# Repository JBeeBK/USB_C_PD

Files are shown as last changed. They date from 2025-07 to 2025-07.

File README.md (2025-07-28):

# USB-C PD Power Meter and Debug Tool

This project is a compact, professional-grade USB-C Power Delivery (PD) debug tool and power meter. **Not finished yet tho.**
It’s designed to showcase modern hardware stuffs (USB-C, PD negotiation, embedded control, current/voltage sensing).
---

## Features

- **USB-C PD Sink (STUSB4500)**: negotiates 5 V / 9 V / 12 V / 15 V / 20 V profiles.  
- **Current and Voltage Monitoring**: INA219 + voltage divider for real-time display.  
- **I²C OLED Menu System**: user-selectable voltage and output control with buttons.  
- **Temperature Monitoring**: TMP112 tracks board temperature for safety.  
- **Visual Indicators**: LEDs show active voltage selection (5 V–20 V).  
- **Output Flexibility**: USB-C and screw terminal outputs (user selects output).  
- **MCU Control**: STM32G030 (TSOP-20) manages I²C devices, UI, and safety cutoffs.  
- **Designed in KiCad 9**: manufacturable layout, not just breadboard-friendly.

---

## Current Status

- **Schematic completed** (`00_Hardware`).  
- **First-round PCB layout completed** (see image below).  
- full check and BOM completion are next

---

## Board Preview

### Top View (First Layout)
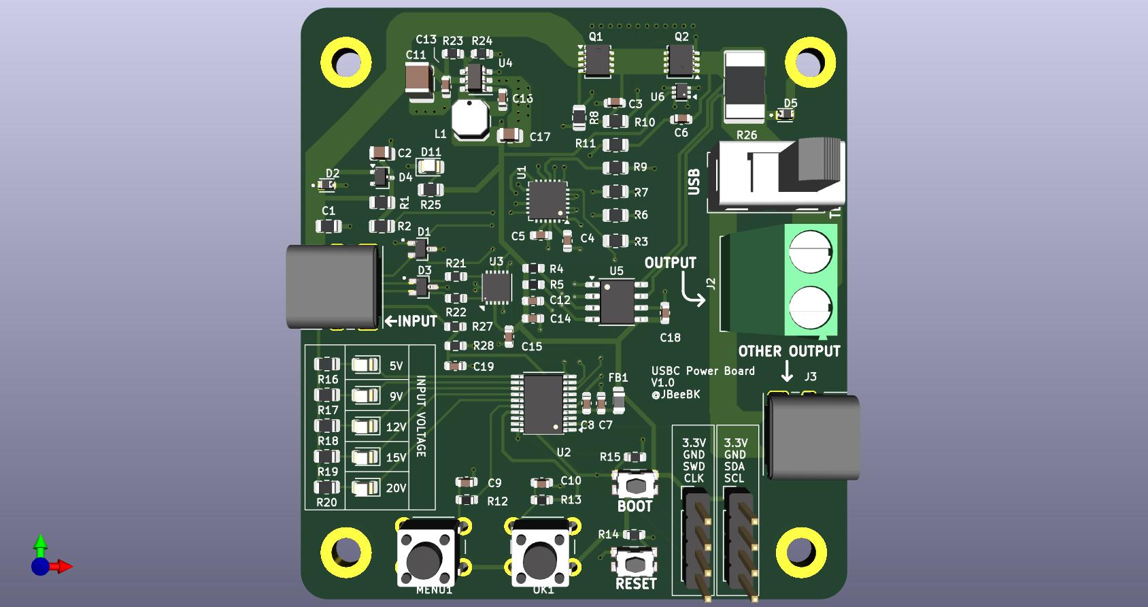
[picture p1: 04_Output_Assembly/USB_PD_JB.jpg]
Board Top


---

## Repository Structure
- 00_Hardware/ # KiCad schematic, PCB, footprints, symbols.
- 01_Docs/ # Design notes, app notes, calculations.
- 02_Datasheets/ # Datasheets here.
- 03_Output_PCB/ # Gerbers.
- 04_Output_Assembly/ # Board renders and fabrication files.
- USB_PD_JB-backups/ # Auto-saved KiCad backups
- output generator python script
- README.md
- .gitignore

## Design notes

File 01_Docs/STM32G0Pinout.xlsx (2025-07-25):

STM32G030F6 | Mapping | TSOP-20
Pin | Name | Function
1 | PB7 | Nope
2 | PB9 | I2C_SCL
3 | PC15 | Nope
4 | VDD | 3.3V
5 | VSS | GND
6 | NRST | Reset
7 | PA0 | Button 1
8 | PA1 | Button 2
9 | PA2 | UART RX
10 | PA3 | UART TX
11 | PA4 | LED_5V
12 | PA5 | LED_9V
13 | PA6 | LED_12V
14 | PA7 | LED_15V
15 | PA8 | LED_20V
16 | PA9 | Nope
17 | PA10 | Nope
18 | PA13 | SWDIO
19 | PA15 | BOOT/SDWCLK
20 | PB3 | I2C_SDA

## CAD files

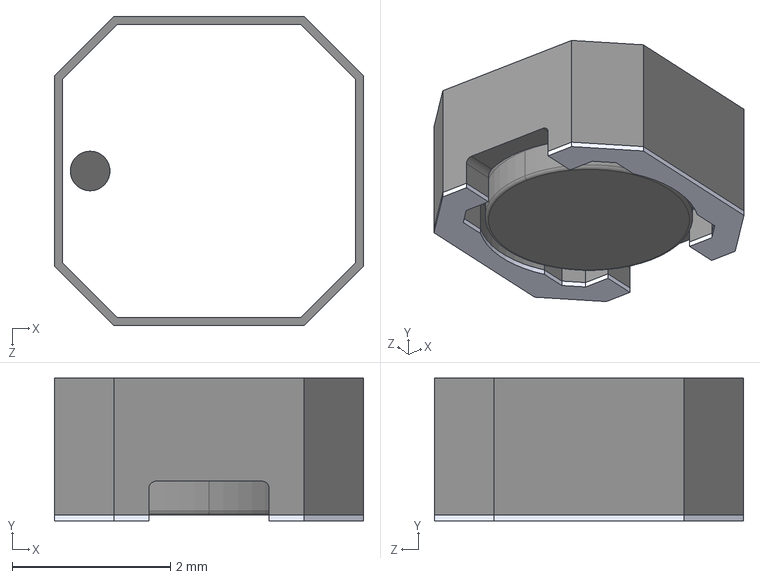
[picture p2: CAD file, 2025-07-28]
00_Hardware/Project_Footprints/LPS4018-103MRC.STEP
3.90 x 1.80 x 3.90 mm

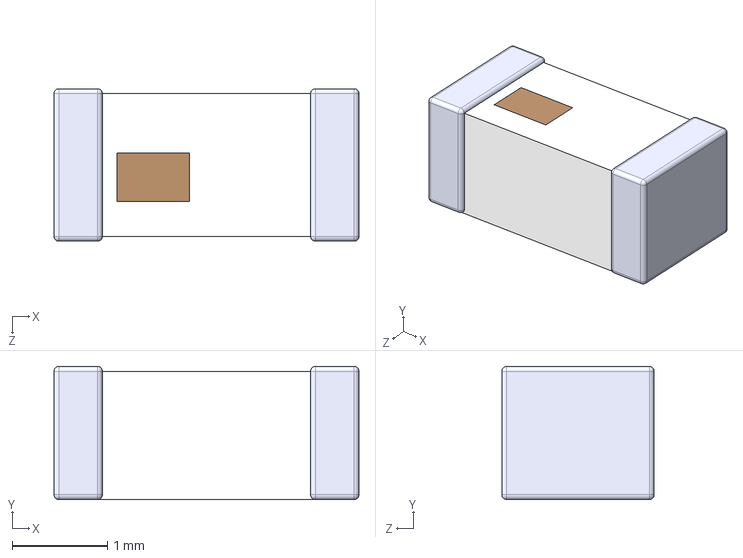
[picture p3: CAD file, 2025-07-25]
00_Hardware/Project_Footprints/2450AT18B100E.step
3.20 x 1.40 x 1.60 mm

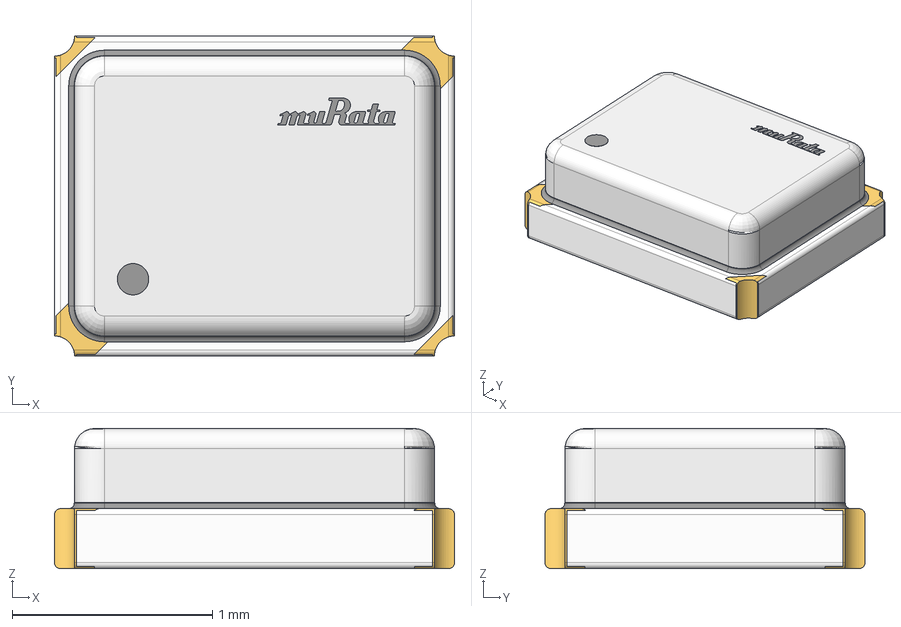
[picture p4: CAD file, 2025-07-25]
00_Hardware/Project_Footprints/XRCGB32M000F1SBJR0-.STEP
2.00 x 1.60 x 0.702 mm

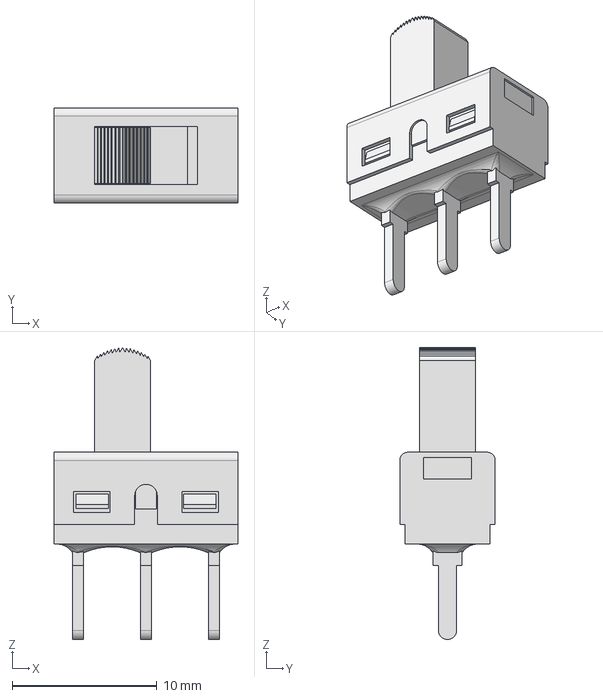
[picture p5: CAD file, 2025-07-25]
00_Hardware/Project_Footprints/500SSP1S2M2QEA.step
12.7 x 6.60 x 20.2 mm

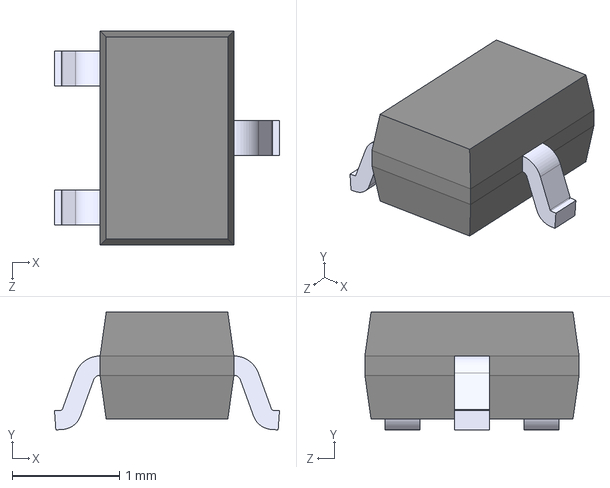
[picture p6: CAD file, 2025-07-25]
00_Hardware/Project_Footprints/ESDA25W.step
2.10 x 1.10 x 2.00 mm

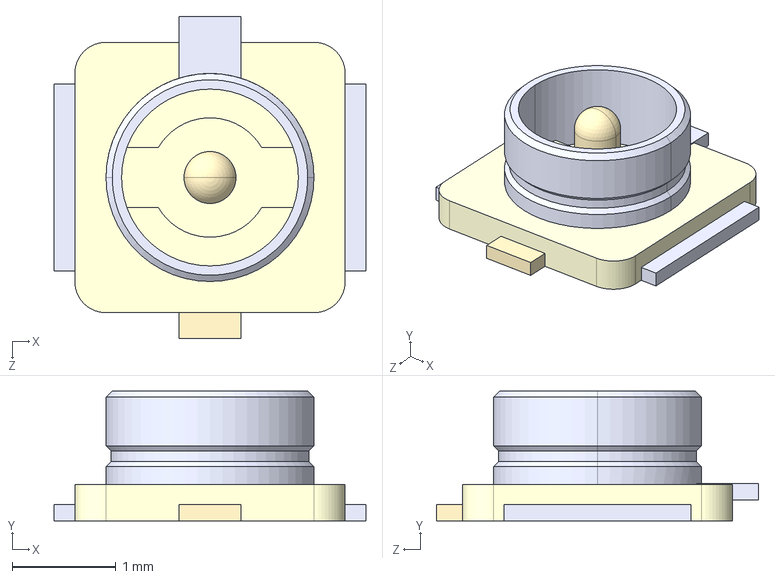
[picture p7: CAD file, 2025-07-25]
00_Hardware/Project_Footprints/U.FL-R-SMT_01_.step
3.00 x 1.25 x 3.10 mm

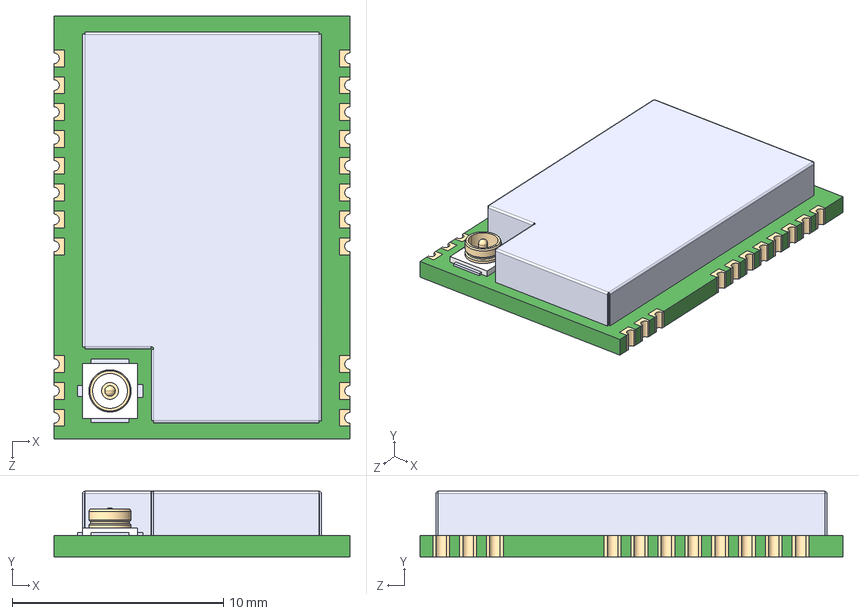
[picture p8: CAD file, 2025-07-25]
00_Hardware/Project_Footprints/E22-900M22S.step
14.0 x 3.10 x 20.0 mm

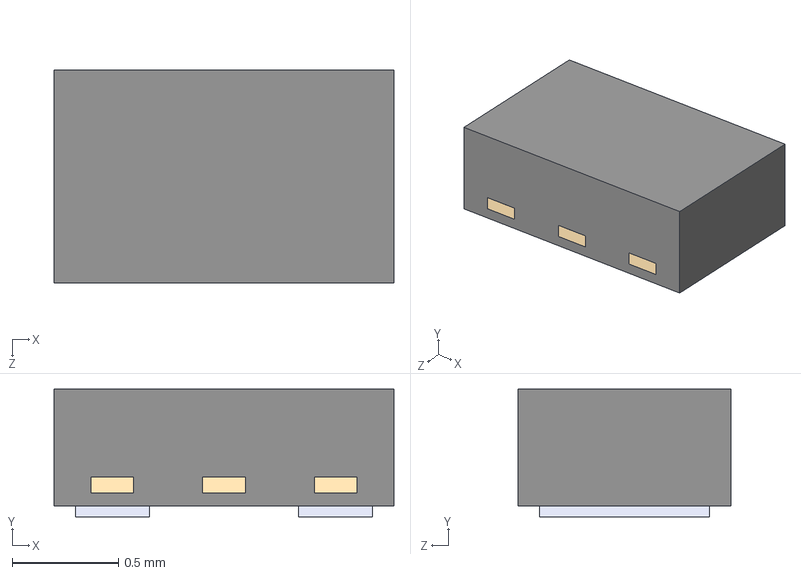
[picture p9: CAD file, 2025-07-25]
00_Hardware/Project_Footprints/ESDA25P35-1U1M.step
1.60 x 0.6 x 1.00 mm

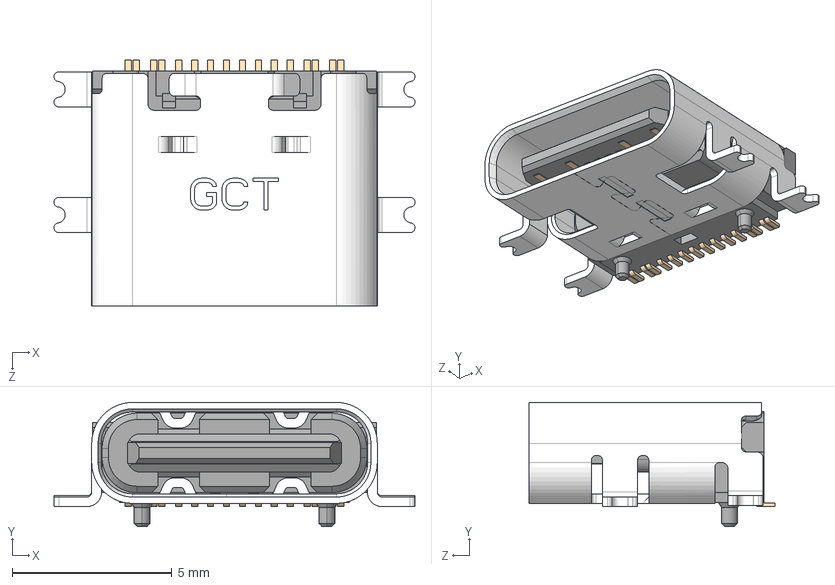
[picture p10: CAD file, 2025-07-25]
00_Hardware/Project_Footprints/USB4110-GF-A.stp
11.3 x 3.89 x 7.70 mm

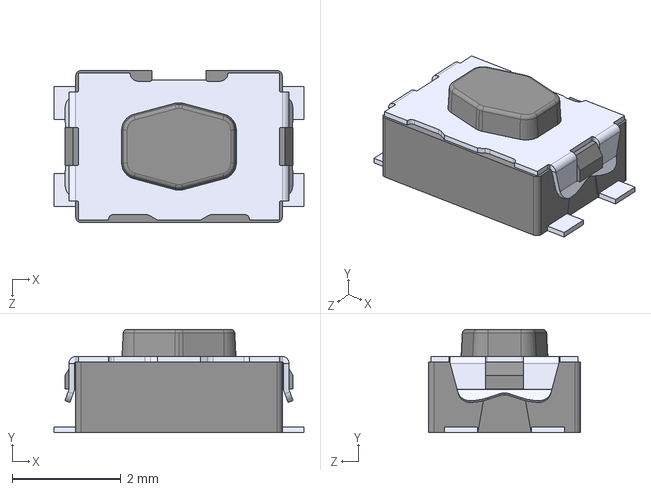
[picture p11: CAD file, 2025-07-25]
00_Hardware/Project_Footprints/KMR211NGLFS.STEP
4.60 x 1.90 x 2.80 mm

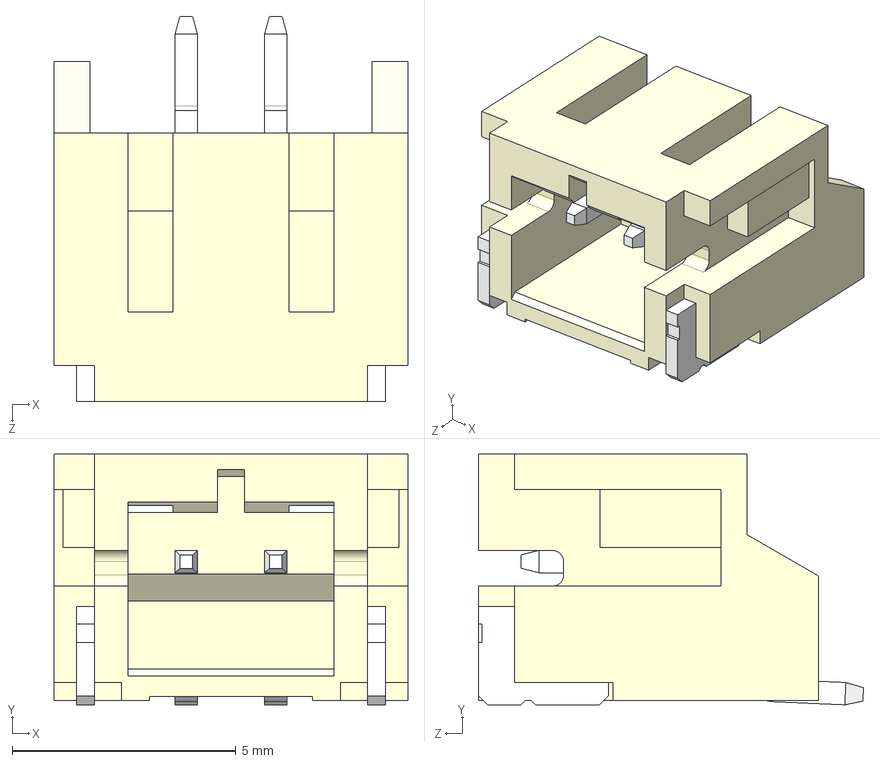
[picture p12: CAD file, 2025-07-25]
00_Hardware/Project_Footprints/S2B-PH-SM4-TB_LF__SN_.step
7.90 x 5.60 x 8.60 mm

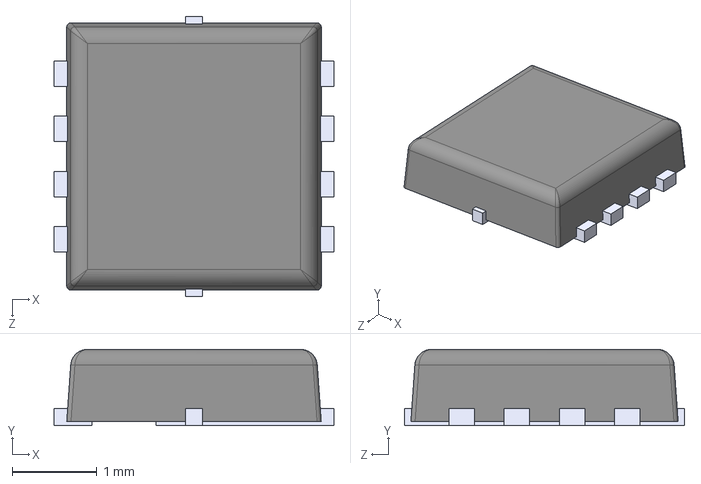
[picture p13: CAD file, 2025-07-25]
00_Hardware/Project_Footprints/STL6P3LLH6.step
3.30 x 0.9 x 3.30 mm

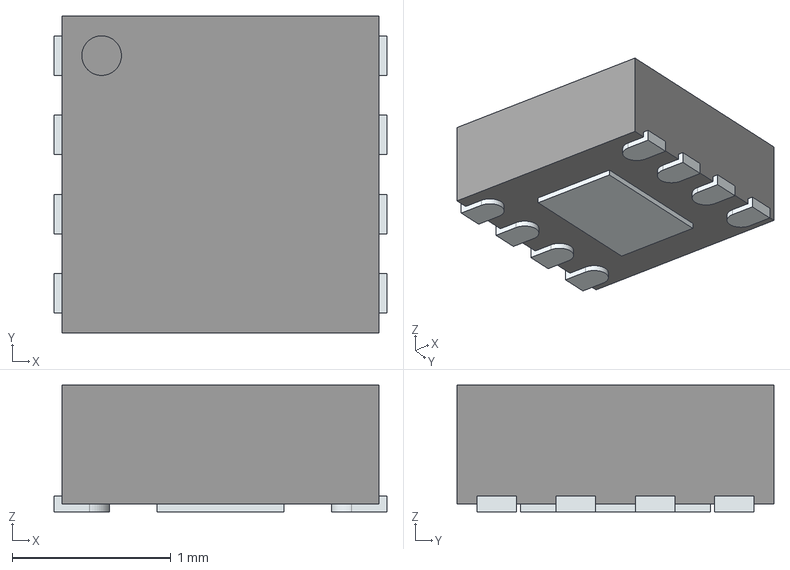
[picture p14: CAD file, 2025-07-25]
00_Hardware/Project_Footprints/MAX17048G+T10.stp
2.10 x 2.00 x 0.8 mm
ThermalPin
PinsArrayLR

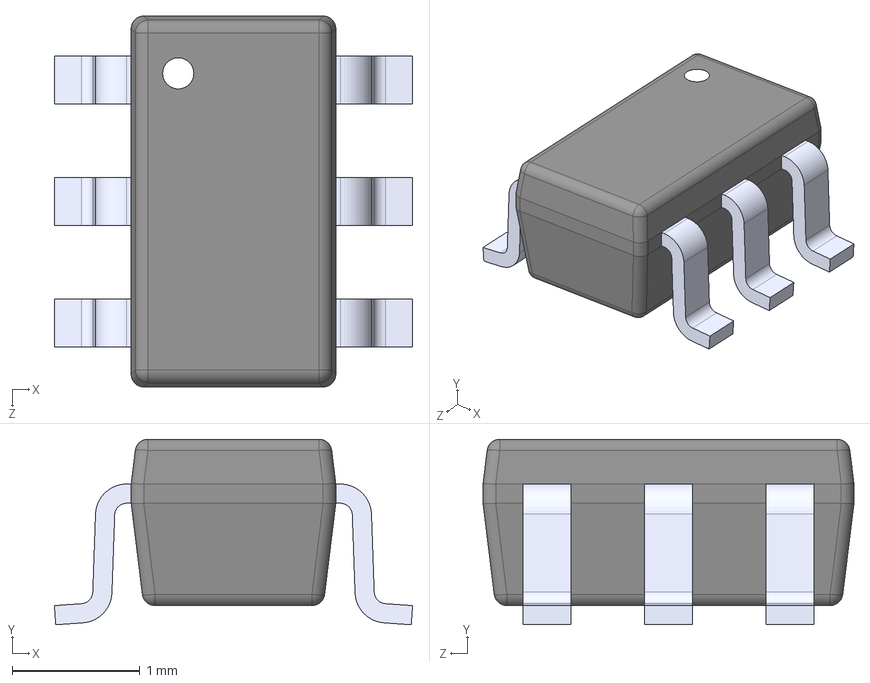
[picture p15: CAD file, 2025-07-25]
00_Hardware/Project_Footprints/TPS560430X3FDBVR.step
2.80 x 1.45 x 2.90 mm

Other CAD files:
00_Hardware/Project_Footprints/nRF52840-QFAA-F-R7.stp

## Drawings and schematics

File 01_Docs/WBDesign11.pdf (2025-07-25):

## WEBENCH ® Design Report

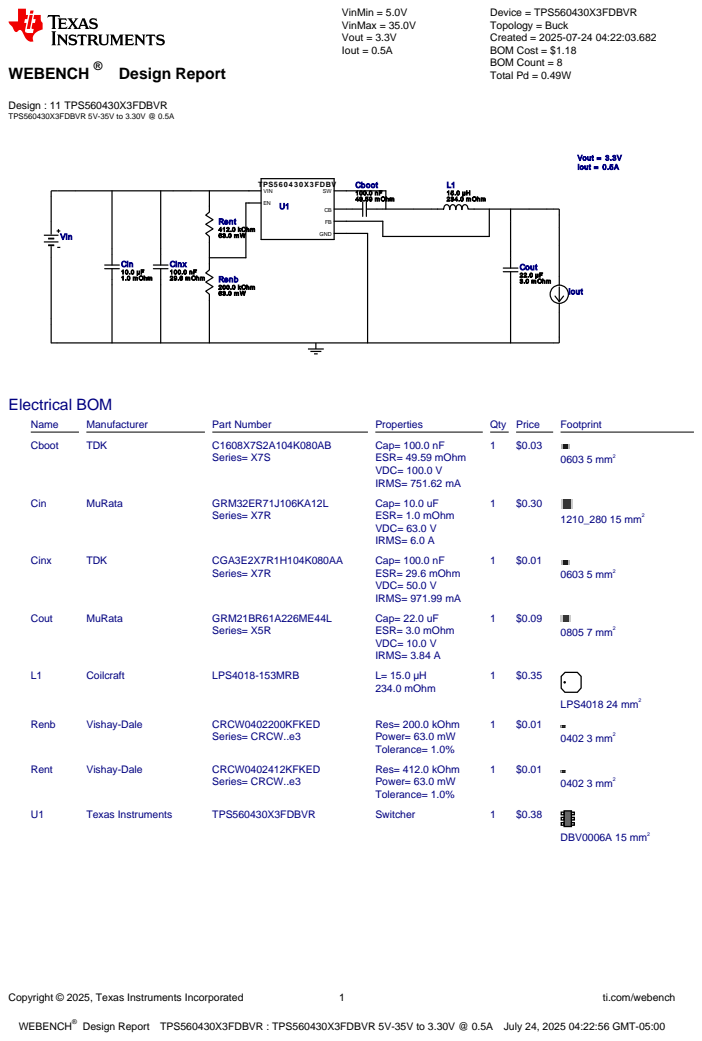
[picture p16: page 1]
Copyright © 2025, Texas Instruments Incorporated; ti.com/webench; WEBENCH®; Design : 11 TPS560430X3FDBVR TPS560430X3FDBVR 5V-35V to 3.30V @ 0.5A; VinMin = 5.0V VinMax = 35.0V Vout = 3.3V Iout = 0.5A; Device = TPS560430X3FDBVR Topology = Buck Created = 2025-07-24 04:22:03.682 BOM Cost = $1.18 BOM Count = 8 Total Pd = 0.49W; Cboot 100.0 nF 49.59 m Ohm; Renb 200.0 kOhm 63.0 m W; Vout = 3.3V Iout = 0.5A; Cin 10.0 µF 1.0 m Ohm; Cout 22.0 µF 3.0 m Ohm; Rent 412.0 kOhm 63.0 m W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

Design Report TPS560430X3FDBVR : TPS560430X3FDBVR 5V-35V to 3.30V @ 0.5A July 24, 2025 04:22:56 GMT-05:00

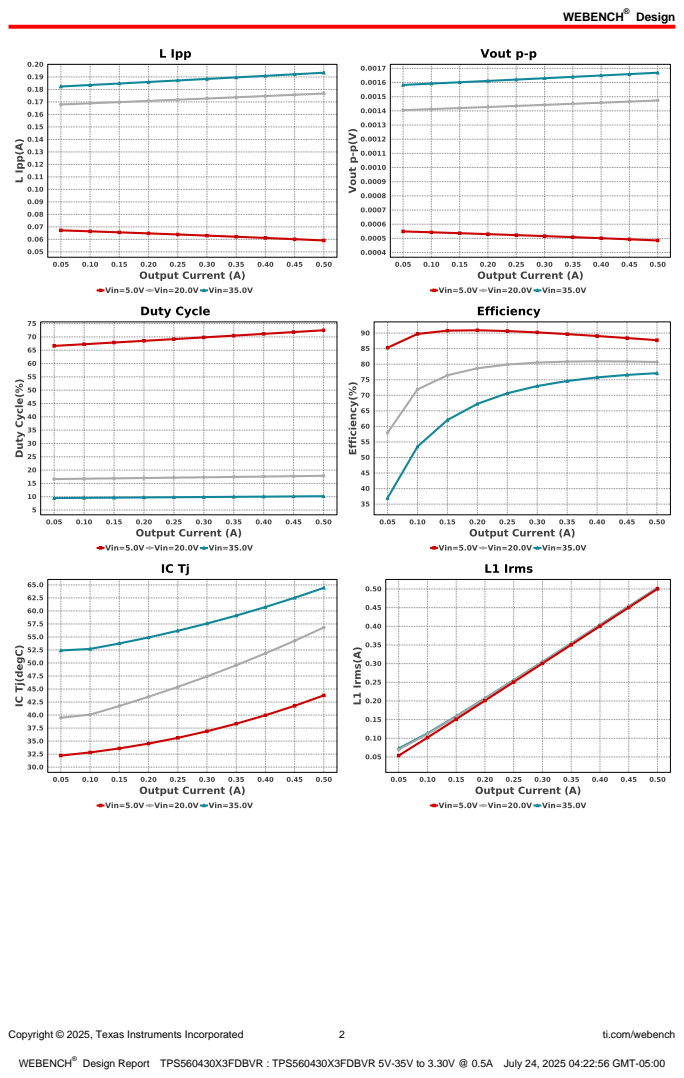
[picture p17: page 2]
Design; Copyright © 2025, Texas Instruments Incorporated; ti.com/webench

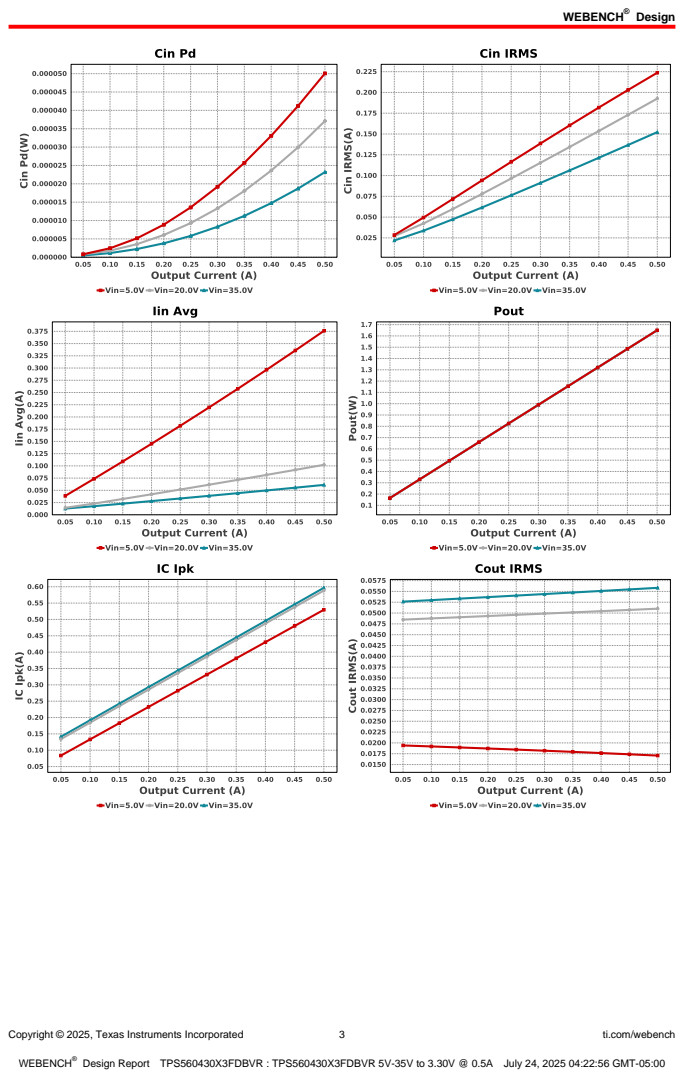
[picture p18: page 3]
Copyright © 2025, Texas Instruments Incorporated; ti.com/webench

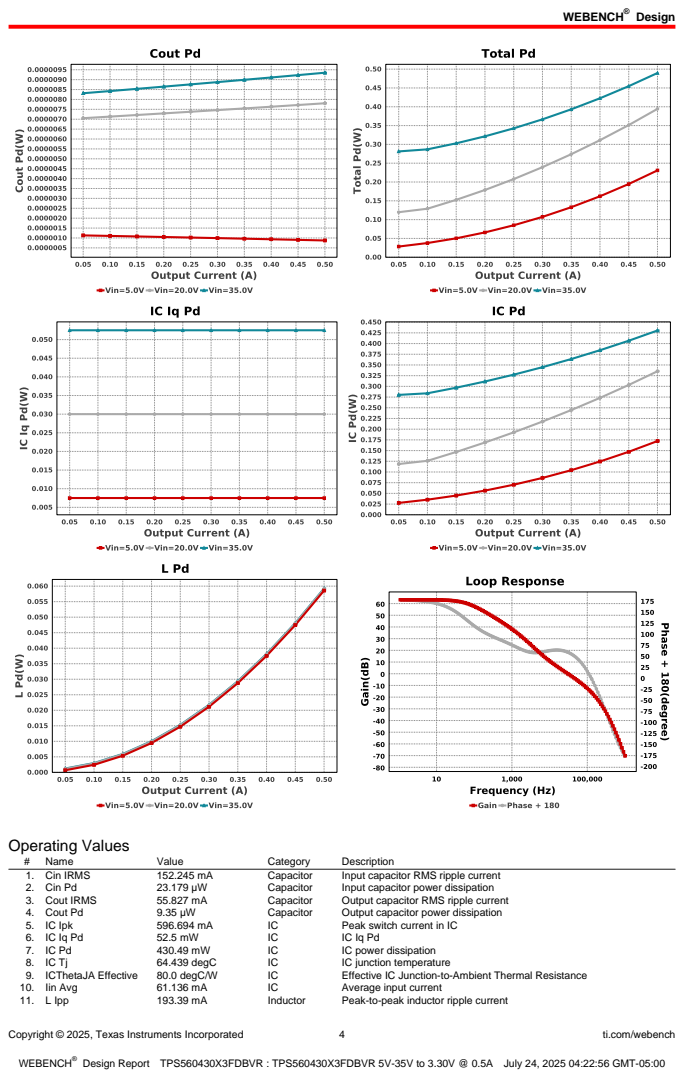
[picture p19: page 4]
Copyright © 2025, Texas Instruments Incorporated; ti.com/webench; Operating Values; Name; Value; Category; Description; 1. Cin IRMS; Capacitor; Input capacitor RMS ripple current; 2. Cin Pd; Input capacitor power dissipation; 3. Cout IRMS; Output capacitor RMS ripple current; 4. Cout Pd; Output capacitor power dissipation; 5. IC Ipk; Peak switch current in IC; IC power dissipation; 64.439 degC; IC junction temperature; 9. ICThetaJA Effective; 80.0 degC/W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

Copyright © 2025, Texas Instruments Incorporated | 5 | ti.com/webench
# | Name | Value | Category | Description

12. L Pd | 59.229 mW | Inductor | Inductor power dissipation
13. L1 Irms | 503.107 mA | Inductor | Inductor ripple current
14. Cin Pd | 23.179 µW | Power | Input capacitor power dissipation
15. Cout Pd | 9.35 µW | Power | Output capacitor power dissipation
16. IC Pd | 430.49 mW | Power | IC power dissipation
17. L Pd | 59.229 mW | Power | Inductor power dissipation
18. Total Pd | 489.748 mW | Power | Total Power Dissipation
19. BOM Count | 8 | System
| | | Information | Total Design BOM count
20. Cross Freq | 30.481 kHz | System
| | | Information | Bode plot crossover frequency
21. Duty Cycle | 10.181 % | System
| | | Information | Duty cycle
22. Efficiency | 77.112 % | System
| | | Information | Steady state efficiency
23. FootPrint | 76.0 mm² | System
| | | Information | Total Foot Print Area of BOM components
24. Frequency | 1.1 MHz | System
| | | Information | Switching frequency
25. Gain Marg | -15.935 dB | System
| | | Information | Bode Plot Gain Margin
26. Iout | 500.0 mA | System
| | | Information | Iout operating point
27. Low Freq Gain | 63.273 dB | System
| | | Information | Gain at 1Hz
28. Mode | CCM | System
| | | Information | PWM/PFM Mode
29. Phase Marg | 59.805 deg | System
| | | Information | Bode Plot Phase Margin
30. Pout | 1.65 W | System
| | | Information | Total output power
31. Total BOM | $1.18 | System
| | | Information | Total BOM Cost
32. Vin | 35.0 V | System
| | | Information | Vin operating point
33. Vout p-p | 1.669 mV | System
| | | Information | Peak-to-peak output ripple voltage

## Design Inputs

Name | Value | Description
| Iout | | 500.0 m | Maximum Output Current
VinMax | 35.0 | Maximum input voltage
VinMin | 5.0 | Minimum input voltage
Vout | 3.3 | Output Voltage
| base_pn | | TPS560430X3F | Base Product Number
source | DC | Input Source Type
Ta | 30.0 | Ambient temperature


Copyright © 2025, Texas Instruments Incorporated | 6 | ti.com/webench

## Assembly

## Component Testing

Some published data on components in datasheets such as Capacitor ESR and Inductor DC resistance is based on conservative values that will guarantee that the components always exceed the specification. For design purposes it is usually better to work with typical values. Since this data is not always available it is a good practice to measure the Capacitance and ESR values of Cin and Cout, and the inductance and DC resistance of L1 before assembly of the board. Any large discrepancies in values should be electrically simulated in WEBENCH to check for instabilities and thermally simulated in WebTHERM to make sure critical temperatures are not exceeded.
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

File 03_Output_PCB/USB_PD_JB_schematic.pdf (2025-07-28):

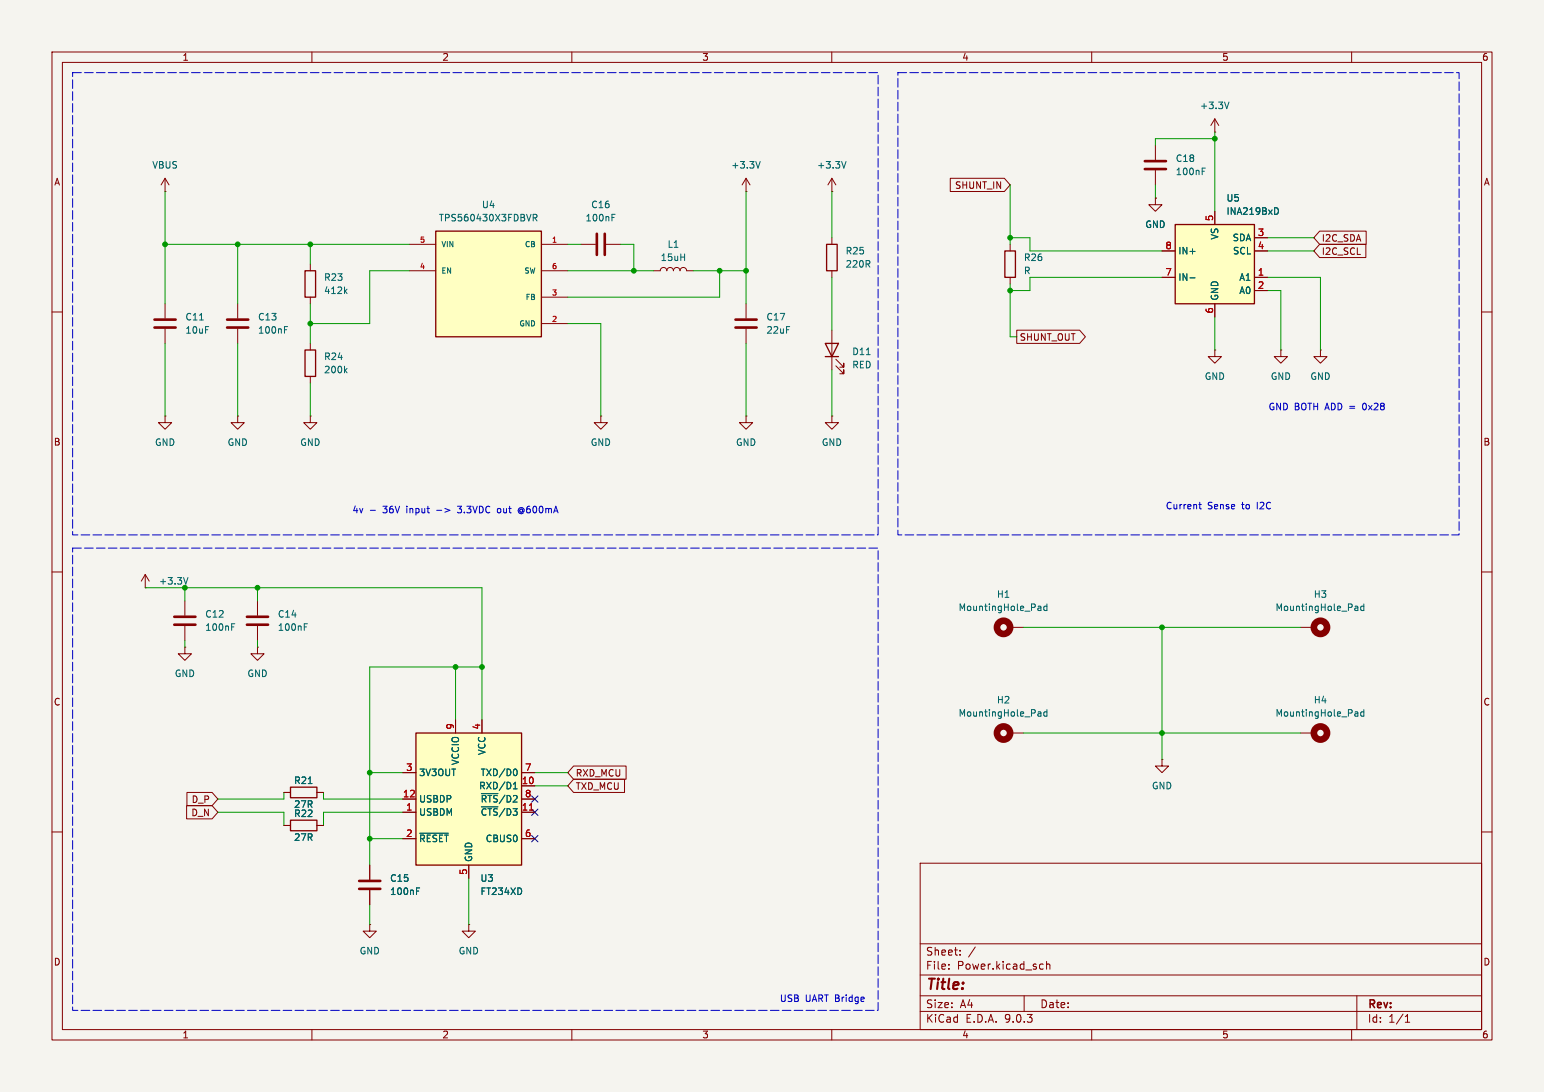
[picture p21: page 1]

4 TXD/D0 7 RXD/D1 10 ~{RTS}/D28 ~{CTS}/D311 CBUS0 6 U3 FT234XD

4 TXD/D0 7 RXD/D1 10 ~{RTS}/D28 ~{CTS}/D311 CBUS0 6

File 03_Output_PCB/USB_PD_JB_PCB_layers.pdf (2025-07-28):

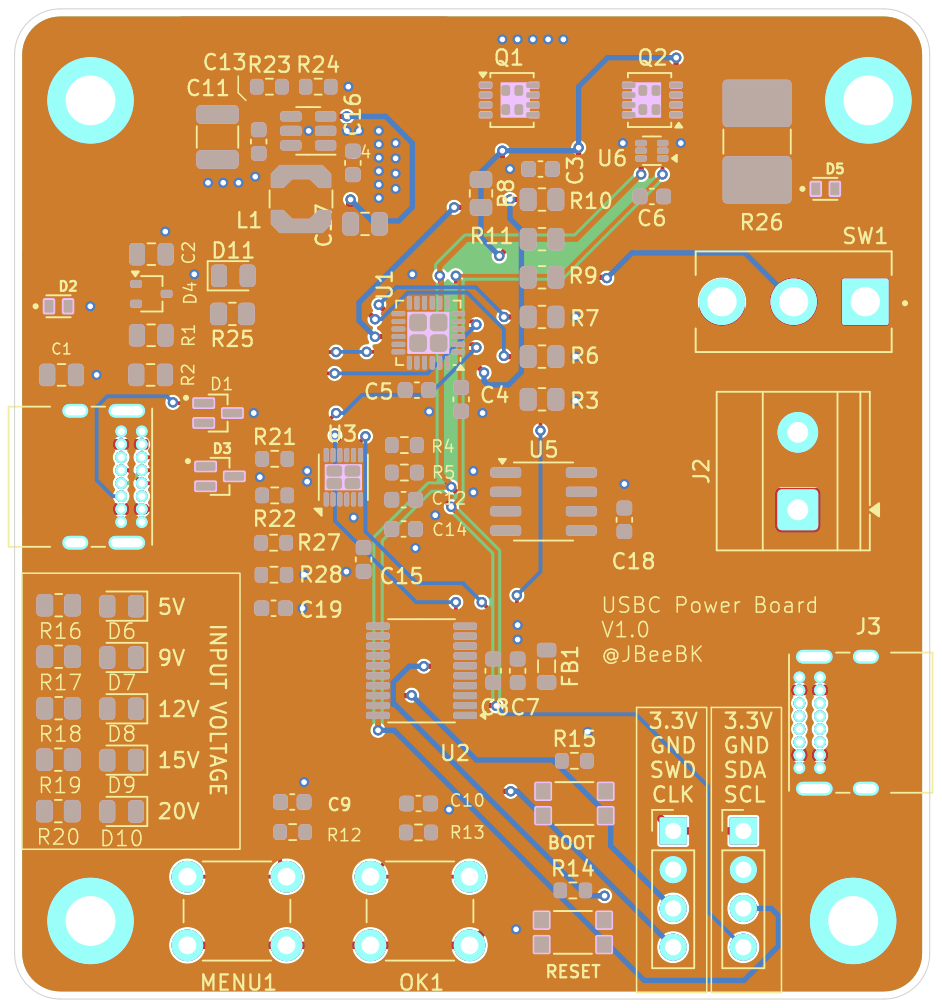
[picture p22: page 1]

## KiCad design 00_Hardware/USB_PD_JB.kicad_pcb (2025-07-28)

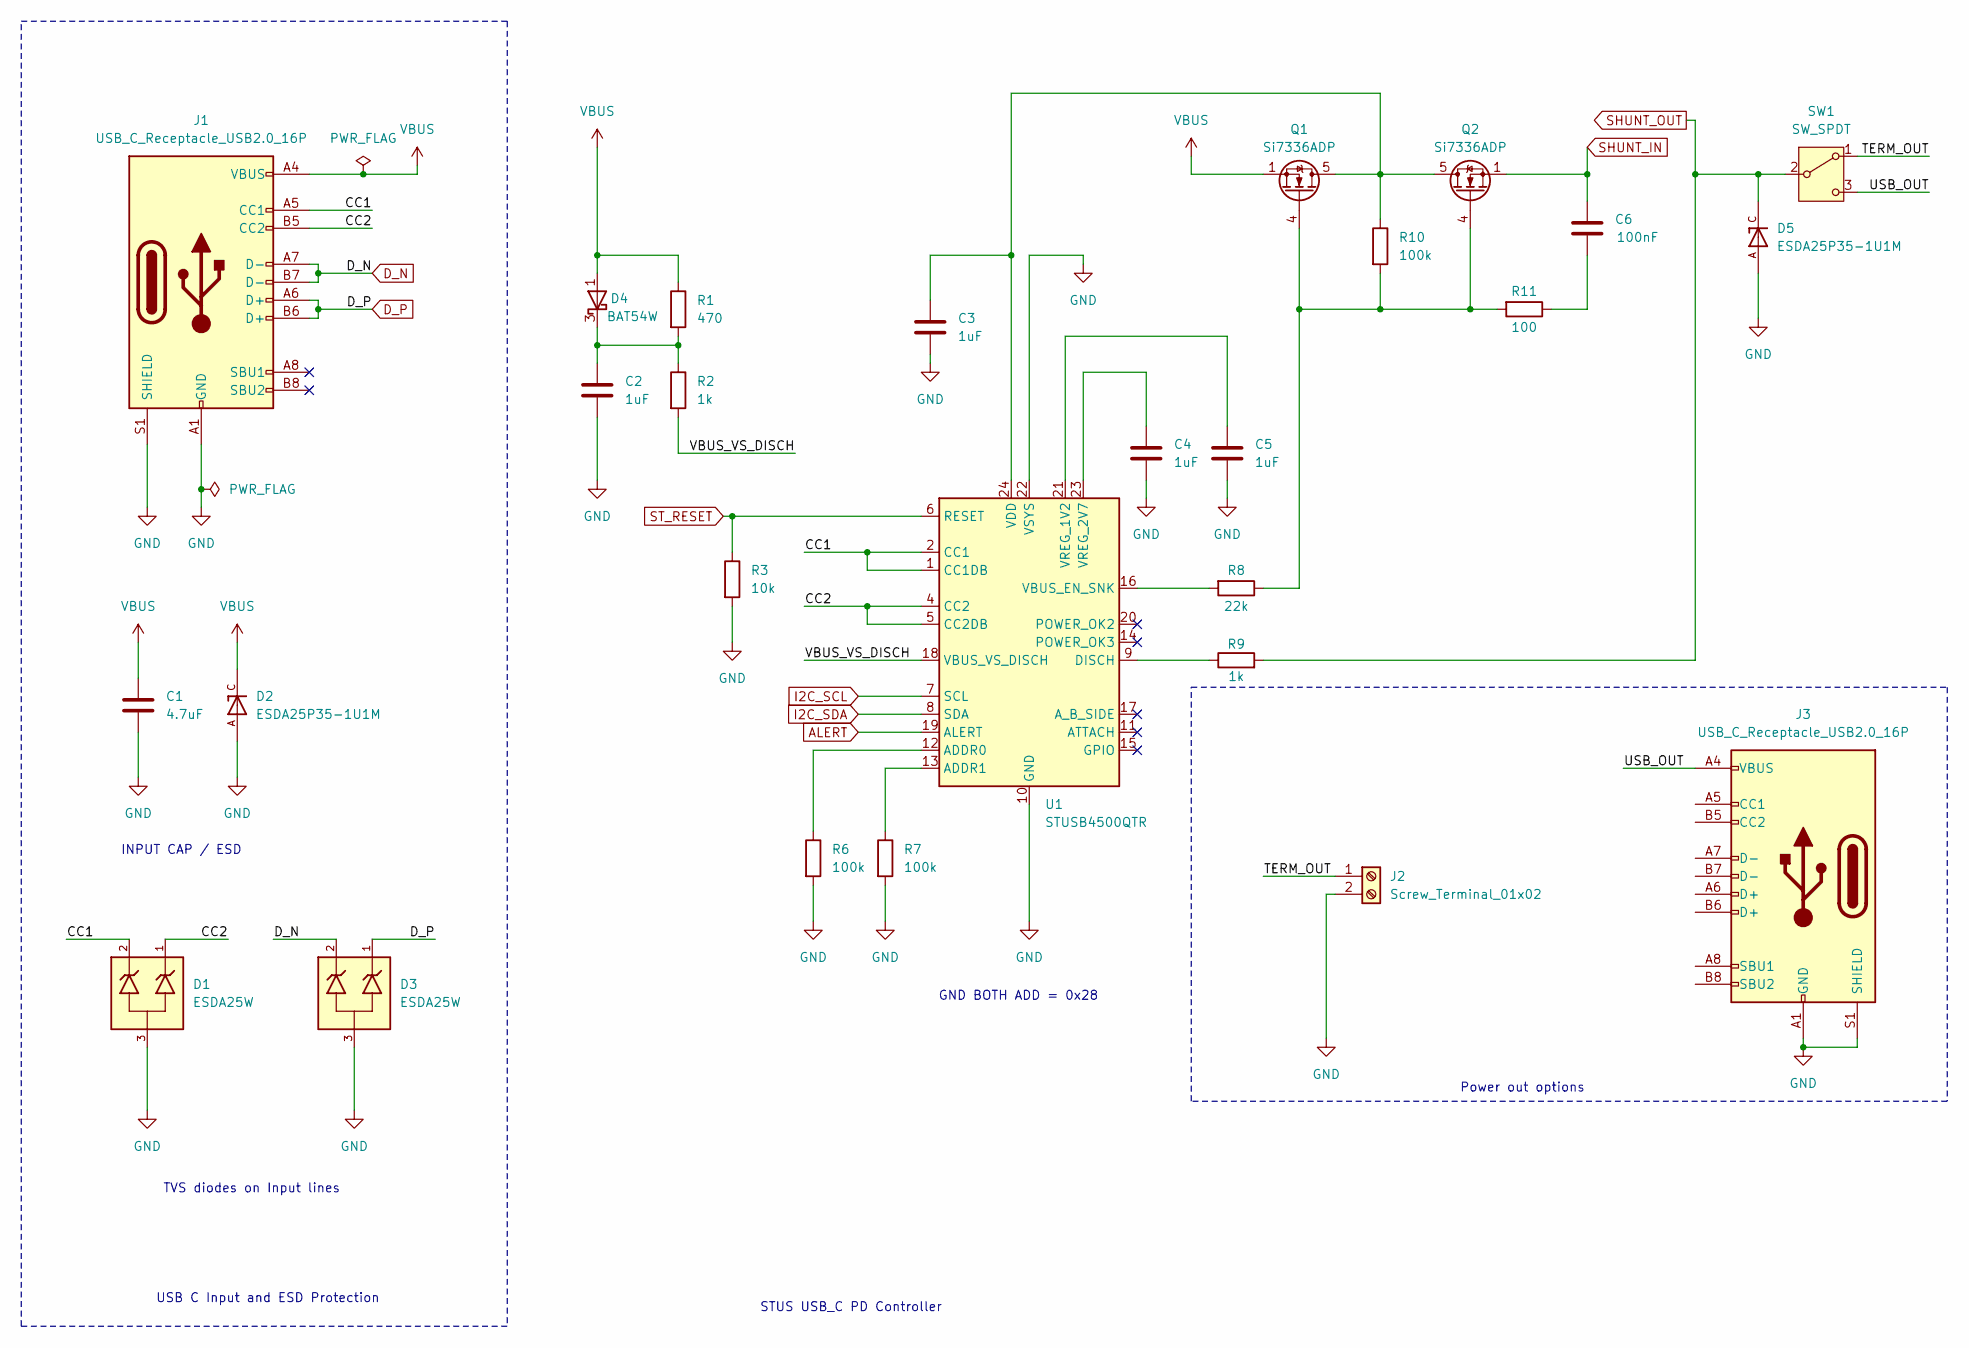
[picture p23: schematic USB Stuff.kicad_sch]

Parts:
C1: 4.7uF; C_0805_2012Metric
C2: 1uF; C_0805_2012Metric
C3, C4, C5: 1uF; C_0603_1608Metric
C6: 100nF; C_0603_1608Metric
D1, D3: ESDA25W; SOT65P210X110-3N; MPN1 ESDA25W
D2, D5: ESDA25P35-1U1M; TVS_ESDA25P35-1U1M; MPN1 ESDA25P35-1U1M
D4: BAT54W; SOT-323_SC-70
J1, J3: USB_C_Receptacle_USB2.0_16P; USB_C_Receptacle_GCT_USB4085
J2: Screw_Terminal_01x02; TerminalBlock_Phoenix_MKDS-1,5-2-5.08_1x02_P5.08mm_Horizont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; MPN1 MKDSN 1,5/2-5,08
Q1, Q2: Si7336ADP; LFPAK33
R1: 470; R_0805_2012Metric
R2, R9: 1k; R_0805_2012Metric
R3: 10k; R_0805_2012Metric
R6, R7, R10: 100k; R_0805_2012Metric
R8: 22k; R_0805_2012Metric
R11: 100; R_0805_2012Metric
SW1: SW_SPDT; 500SSP1S2M2QEA
U1: STUSB4500QTR; QFN-24-1EP_4x4mm_P0.5mm_EP2.7x2.7mm

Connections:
/USB Stuff/CC1: D1.2, J1.A5 (CC1), U1.1 (CC1DB), U1.2 (CC1)
/USB Stuff/CC2: D1.1, J1.B5 (CC2), U1.4 (CC2), U1.5 (CC2DB)
/USB Stuff/TERM_OUT: J2.1, SW1.1 (A)
/USB Stuff/USB_OUT: J3.A4 (VBUS), J3.A9 (VBUS), J3.B4 (VBUS), J3.B9 (VBUS), SW1.3 (C)
/USB Stuff/VBUS_VS_DISCH: R2.2, U1.18 (VBUS_VS_DISCH)
ALERT: U1.19 (ALERT)
D_N: D3.2, J1.A7 (D-), J1.B7 (D-); also elsewhere on the board
D_P: D3.1, J1.A6 (D+), J1.B6 (D+); also elsewhere on the board
GND: C1.2, C2.2, C3.2, C4.2, C5.2, D1.3, D2.A, D3.3, D5.A, J1.A1 (GND), J1.A12 (GND), J1.B1 (GND), J1.B12 (GND), J1.S1 (SHIELD), J2.2, J3.A1 (GND), J3.A12 (GND), J3.B1 (GND), J3.B12 (GND), J3.S1 (SHIELD), R3.2, R6.2, R7.2, U1.10 (GND), U1.22 (VSYS), U1.25 (GND); also elsewhere on the board
I2C_SCL: U1.7 (SCL); also elsewhere on the board
I2C_SDA: U1.8 (SDA); also elsewhere on the board
unnamed: C6.2, R11.1
unnamed: C2.1, D4.3 (K), R1.2, R2.1
unnamed: C3.1, Q1.5 (D), Q2.5 (D), R10.1, U1.24 (VDD)
unnamed: Q1.4 (G), Q2.4 (G), R8.1, R10.2, R11.2
unnamed: R6.1, U1.12 (ADDR0)
unnamed: R7.1, U1.13 (ADDR1)
unnamed: R9.1, U1.9 (DISCH)
unnamed: R8.2, U1.16 (VBUS_EN_SNK)
unnamed: C5.1, U1.21 (VREG_1V2)
unnamed: C4.1, U1.23 (VREG_2V7)
SHUNT_IN: C6.1, Q2.1 (S), Q2.2 (S), Q2.3 (S); also elsewhere on the board
SHUNT_OUT: D5.C, R9.2, SW1.2 (B); also elsewhere on the board
ST_RESET: R3.1, U1.6 (RESET); also elsewhere on the board
VBUS: C1.1, D2.C, D4.1 (A), J1.A4 (VBUS), J1.A9 (VBUS), J1.B4 (VBUS), J1.B9 (VBUS), Q1.1 (S), Q1.2 (S), Q1.3 (S), R1.1; also elsewhere on the board

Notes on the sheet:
Power out options
USB C Input and ESD Protection
GND BOTH ADD = 0x28
TVS diodes on Input lines
INPUT CAP / ESD
STUS USB_C PD Controller

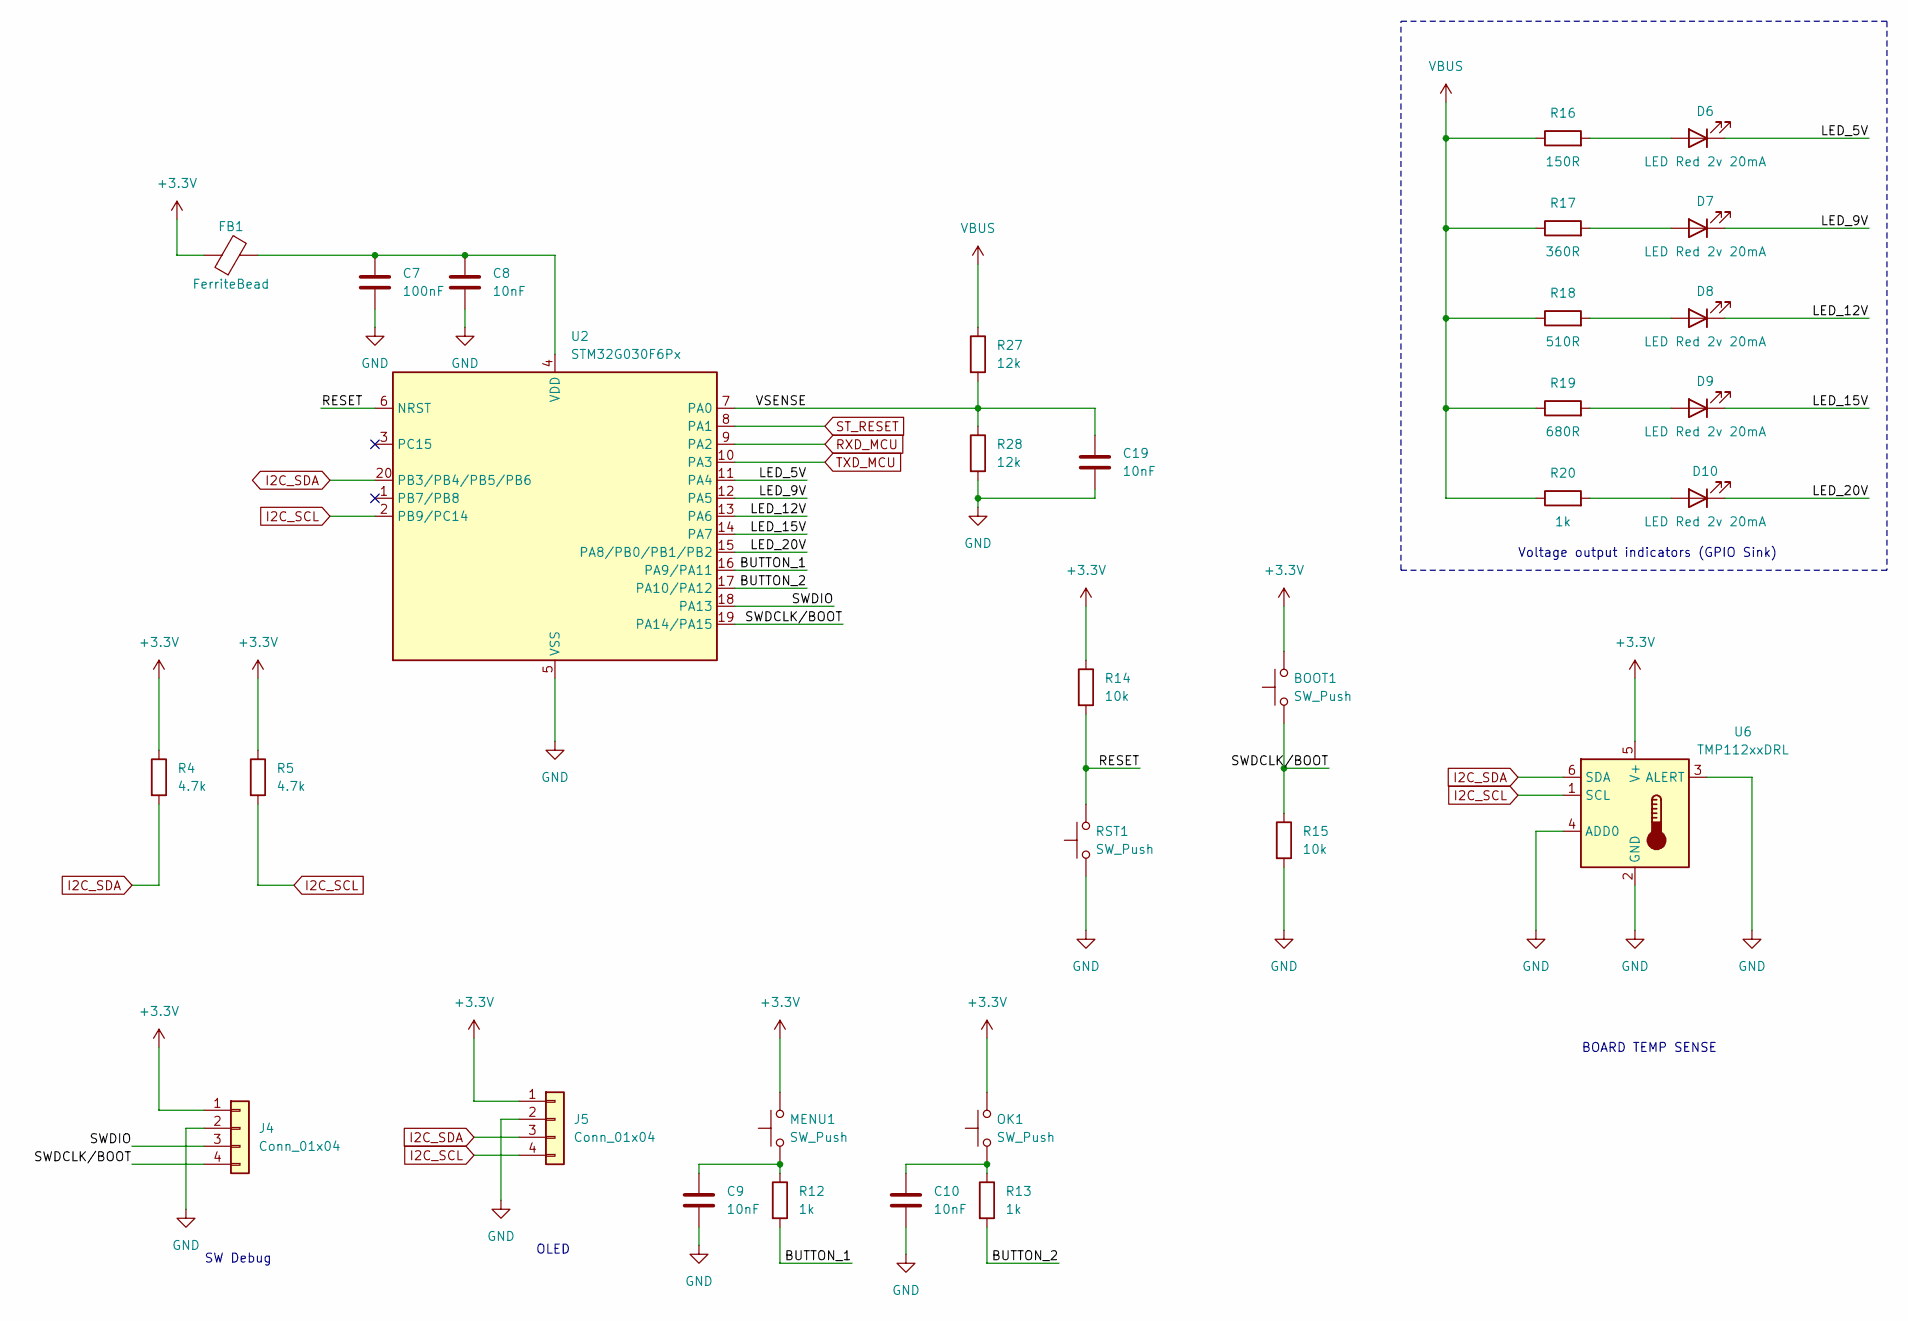
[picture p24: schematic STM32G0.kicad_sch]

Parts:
BOOT1: SW_Push; KMR211NGLFS
C7: 100nF; C_0603_1608Metric
C8, C9, C10, C19: 10nF; C_0603_1608Metric
D6, D7, D8, D9, D10: LED Red 2v 20mA; LED_0805_2012Metric; MPN1 APT2012SYCK
FB1: FerriteBead; L_0805_2012Metric
J4, J5: Conn_01x04; PinHeader_1x04_P2.54mm_Vertical
MENU1: SW_Push; SW_PUSH_6mm_H5mm
OK1: SW_Push; SW_PUSH_6mm_H5mm
R4, R5: 4.7k; R_0603_1608Metric
R12, R13: 1k; R_0603_1608Metric
R14, R15: 10k; R_0603_1608Metric
R16: 150R; R_0805_2012Metric
R17: 360R; R_0805_2012Metric
R18: 510R; R_0805_2012Metric
R19: 680R; R_0805_2012Metric
R20: 1k; R_0805_2012Metric
R27, R28: 12k; R_0603_1608Metric
RST1: SW_Push; KMR211NGLFS
U2: STM32G030F6Px; TSSOP-20_4.4x6.5mm_P0.65mm
U6: TMP112xxDRL; SOT-563

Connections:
+3.3V: BOOT1.2, FB1.1, J4.1, J5.1, MENU1.2, OK1.2, R4.1, R5.1, R14.1, U6.5 (V+); also elsewhere on the board
/STM32G0/BUTTON_1: R12.2, U2.16 (PA9/PA11)
/STM32G0/BUTTON_2: R13.2, U2.17 (PA10/PA12)
/STM32G0/LED_5V: D6.1 (K), U2.11 (PA4)
/STM32G0/LED_9V: D7.1 (K), U2.12 (PA5)
/STM32G0/LED_12V: D8.1 (K), U2.13 (PA6)
/STM32G0/LED_15V: D9.1 (K), U2.14 (PA7)
/STM32G0/LED_20V: D10.1 (K), U2.15 (PA8/PB0/PB1/PB2)
/STM32G0/RESET: R14.2, RST1.2, U2.6 (NRST)
/STM32G0/SWDCLK/BOOT: BOOT1.1, J4.4, R15.1, U2.19 (PA14/PA15)
/STM32G0/SWDIO: J4.3, U2.18 (PA13)
/STM32G0/VSENSE: C19.1, R27.2, R28.1, U2.7 (PA0)
GND: C7.2, C8.2, C9.2, C10.2, C19.2, J4.2, J5.2, R15.2, R28.2, RST1.1, U2.5 (VSS), U6.2 (GND), U6.3 (ALERT), U6.4 (ADD0); also elsewhere on the board
I2C_SCL: J5.4, R5.2, U2.2 (PB9/PC14), U6.1 (SCL); also elsewhere on the board
I2C_SDA: J5.3, R4.2, U2.20 (PB3/PB4/PB5/PB6), U6.6 (SDA); also elsewhere on the board
unnamed: C9.1, MENU1.1, R12.1
unnamed: C10.1, OK1.1, R13.1
unnamed: D6.2 (A), R16.2
unnamed: D7.2 (A), R17.2
unnamed: D8.2 (A), R18.2
unnamed: D9.2 (A), R19.2
unnamed: D10.2 (A), R20.2
unnamed: C7.1, C8.1, FB1.2, U2.4 (VDD)
RXD_MCU: U2.9 (PA2); also elsewhere on the board
ST_RESET: U2.8 (PA1); also elsewhere on the board
TXD_MCU: U2.10 (PA3); also elsewhere on the board
VBUS: R16.1, R17.1, R18.1, R19.1, R20.1, R27.1; also elsewhere on the board

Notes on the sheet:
OLED
BOARD TEMP SENSE
SW Debug
Voltage output indicators (GPIO Sink)

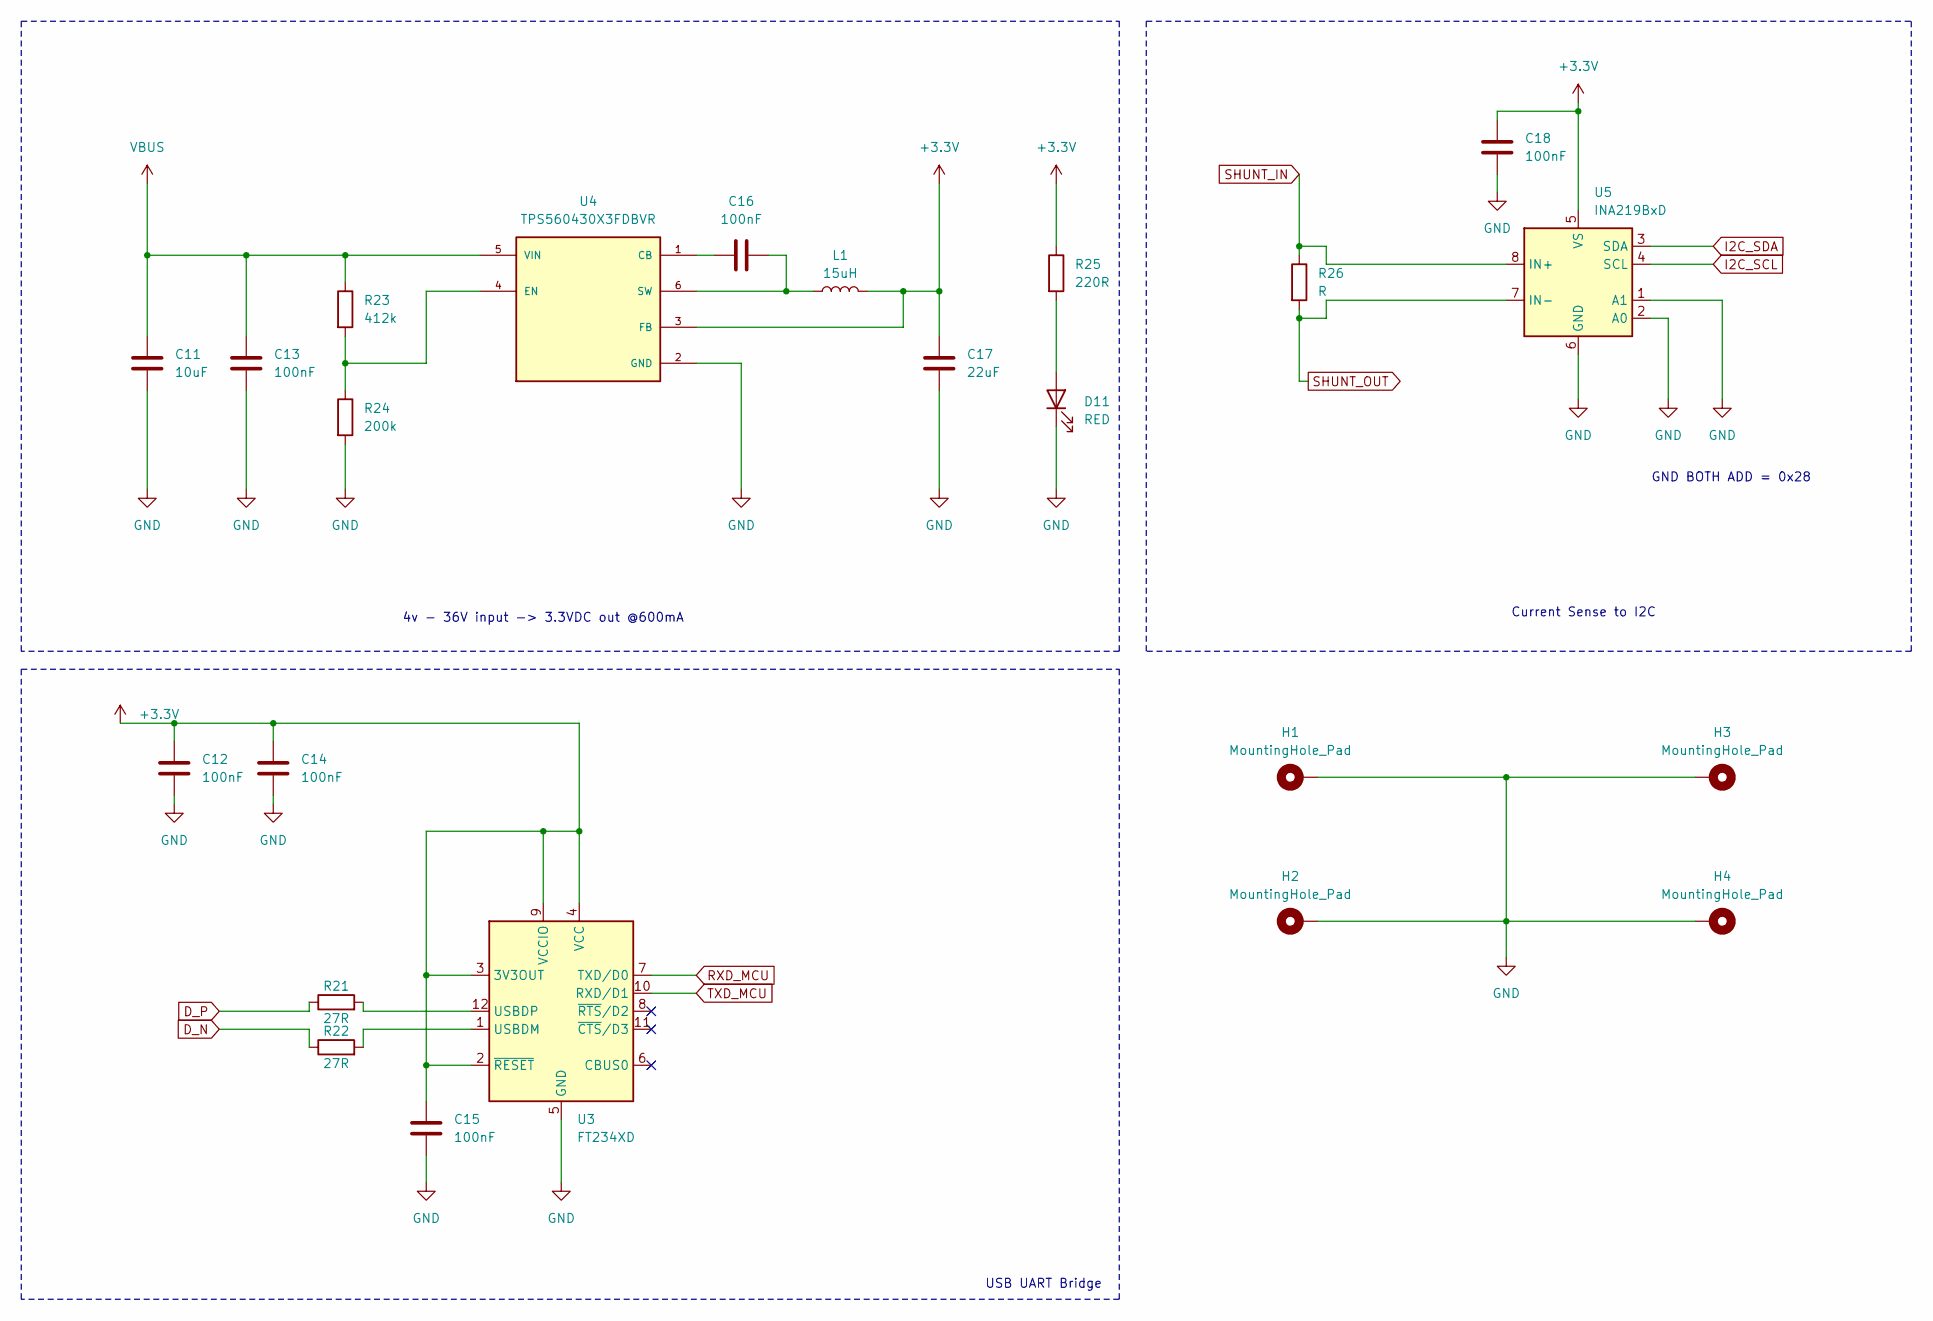
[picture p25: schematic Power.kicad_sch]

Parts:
C11: 10uF; C_1210_3225Metric; MPN1 GRM32ER71J106KA12L
C12, C13, C14, C15, C16, C18: 100nF; C_0603_1608Metric
C17: 22uF; C_0805_2012Metric
D11: RED; LED_0805_2012Metric; MPN1 APT2012SURCK
H1, H2, H3, H4: MountingHole_Pad; MountingHole_3.2mm_M3_DIN965_Pad_TopBottom
L1: 15uH; L_Coilcraft_LPS4018; MPN1 LPS4018-153MR
R21, R22: 27R; R_0603_1608Metric
R23: 412k; R_0603_1608Metric
R24: 200k; R_0603_1608Metric
R25: 220R; R_0805_2012Metric
R26: R; R_2816_7142Metric; MPN1 WSL2512R0100FEA
U3: FT234XD; DFN-12-1EP_3x3mm_P0.45mm_EP1.65x2.38mm
U4: TPS560430X3FDBVR; SOT-23-6; PARTREV B
U5: INA219BxD; SOIC-8_3.9x4.9mm_P1.27mm

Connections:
+3.3V: C12.1, C14.1, C15.1, C17.1, C18.1, L1.2, R25.1, U3.2 (~RESET), U3.3 (3V3OUT), U3.4 (VCC), U3.9 (VCCIO), U4.3 (FB), U5.5 (VS); also elsewhere on the board
D_N: R22.1; also elsewhere on the board
D_P: R21.1; also elsewhere on the board
GND: C11.2, C12.2, C13.2, C14.2, C15.2, C17.2, C18.2, D11.1 (K), H1.1, H2.1, H3.1, H4.1, R24.2, U3.5 (GND), U3.13 (GND), U4.2 (GND), U5.1 (A1), U5.2 (A0), U5.6 (GND); also elsewhere on the board
I2C_SCL: U5.4 (SCL); also elsewhere on the board
I2C_SDA: U5.3 (SDA); also elsewhere on the board
unnamed: D11.2 (A), R25.2
unnamed: R22.2, U3.1 (USBDM)
unnamed: R21.2, U3.12 (USBDP)
unnamed: C16.1, U4.1 (CB)
unnamed: R23.2, R24.1, U4.4 (EN)
unnamed: C16.2, L1.1, U4.6 (SW)
RXD_MCU: U3.7 (TXD/D0); also elsewhere on the board
SHUNT_IN: R26.1, U5.8 (IN+); also elsewhere on the board
SHUNT_OUT: R26.2, U5.7 (IN-); also elsewhere on the board
TXD_MCU: U3.10 (RXD/D1); also elsewhere on the board
VBUS: C11.1, C13.1, R23.1, U4.5 (VIN); also elsewhere on the board

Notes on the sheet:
Current Sense to I2C
4v - 36V input -> 3.3VDC out @600mA
GND BOTH ADD = 0x28
USB UART Bridge

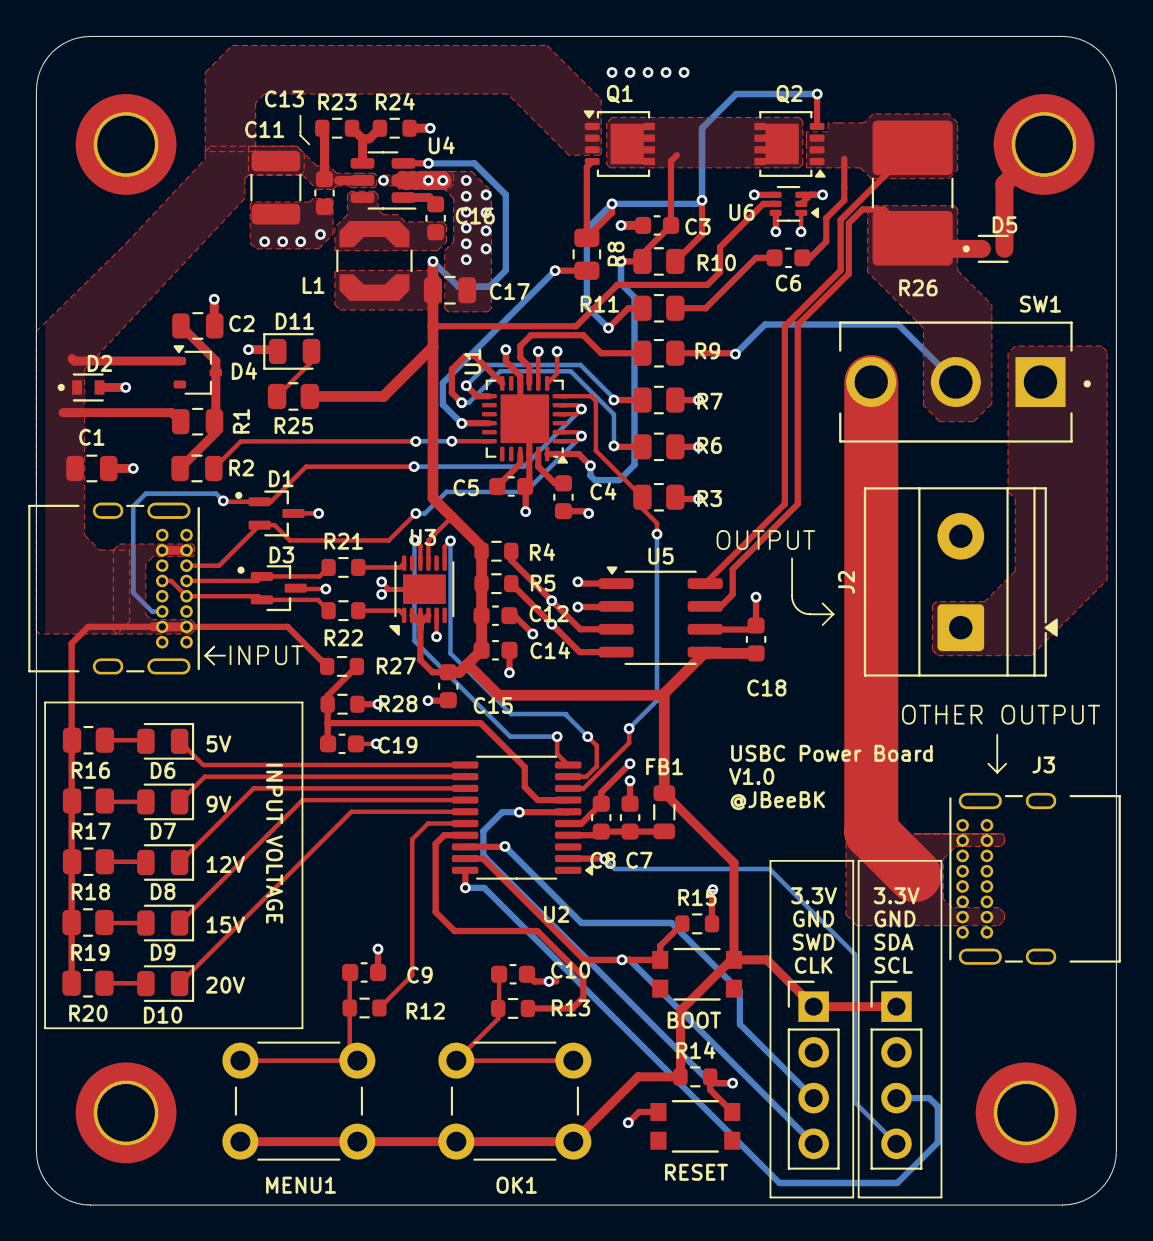
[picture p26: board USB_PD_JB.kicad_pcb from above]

Board: 4 copper layers, 60.0 x 64.9 mm, 82 parts (0 on the bottom side), 52 nets.

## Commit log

2025-07-25 initial commit of schematic, transferring to another PC to continue
    [2450AT18B100E.step, 500SSP1S2M2QEA.step, E22-900M22S.step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]
2025-07-28 First Routing w/ output files auto-generated
    [LPS4018-103MRC.STEP, Power.kicad_sch, RAK3172.step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]
2025-07-29 updated silkscreen
2025-07-29 silkscreen update

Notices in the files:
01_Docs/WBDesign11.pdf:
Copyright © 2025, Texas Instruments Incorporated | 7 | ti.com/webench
